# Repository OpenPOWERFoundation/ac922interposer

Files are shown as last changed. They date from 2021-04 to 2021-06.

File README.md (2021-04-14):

# ac922interposer

The purpose of this design is to enable the AC922 to accept a DC-SCM v1.0 hardware management module.  This enables a developement
platform for software development.

For connection with a DC-SCM, the DC-SCM v1.0 release design specifies the connector as an SFF-TA-1002 compliant 4C+ connector. The 4C+ connector is a 4C compliant connector with an additional 28-pin “OCP bay” defined in the OCP NIC 3.0 specification.  The right-angled variety allows for the DC-SCM to lay within the BMC cage assembly.  This can be implemented with TE 2336568-1.

References:

DC-SCM 0.95 Draft Specification:
https://www.opencompute.org/documents/ocp-dc-scm-spec-rev-0-95-pdf

DC-SCM 2.0 Draft Specification:
https://drive.google.com/file/d/1UkFgAFKh8qz4mAXdvodYsW0fg8XhyVf2/view?usp=sharing

AC922 Specification:
see OpenPower website

SFF-TA-1002 Protocol Agnostic Multi-Lane High Speed Connector
https://members.snia.org/document/dl/27231

AntMicro Design Specification:
https://github.com/antmicro/artix-dc-scm.git

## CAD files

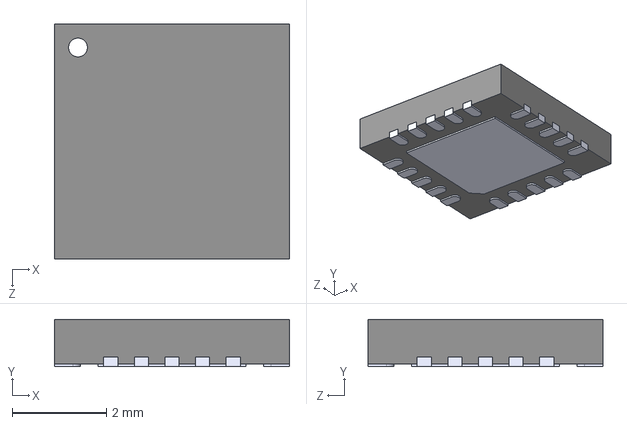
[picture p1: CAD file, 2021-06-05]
3D/TPS7A7100RGWR.STEP
5.00 x 1.00 x 5.00 mm

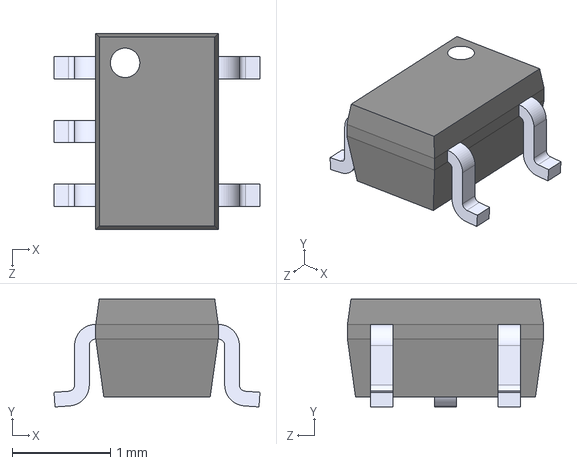
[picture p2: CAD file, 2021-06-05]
kicad-TI_TPS3801/TPS3801K33DCKR.step
2.10 x 1.10 x 2.00 mm

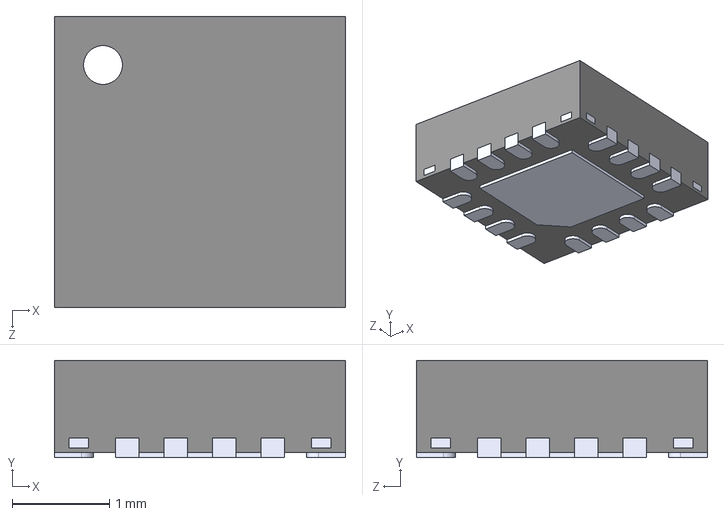
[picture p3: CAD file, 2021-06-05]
3D/TPS7A7100RGTR.STEP
3.00 x 1.00 x 3.00 mm

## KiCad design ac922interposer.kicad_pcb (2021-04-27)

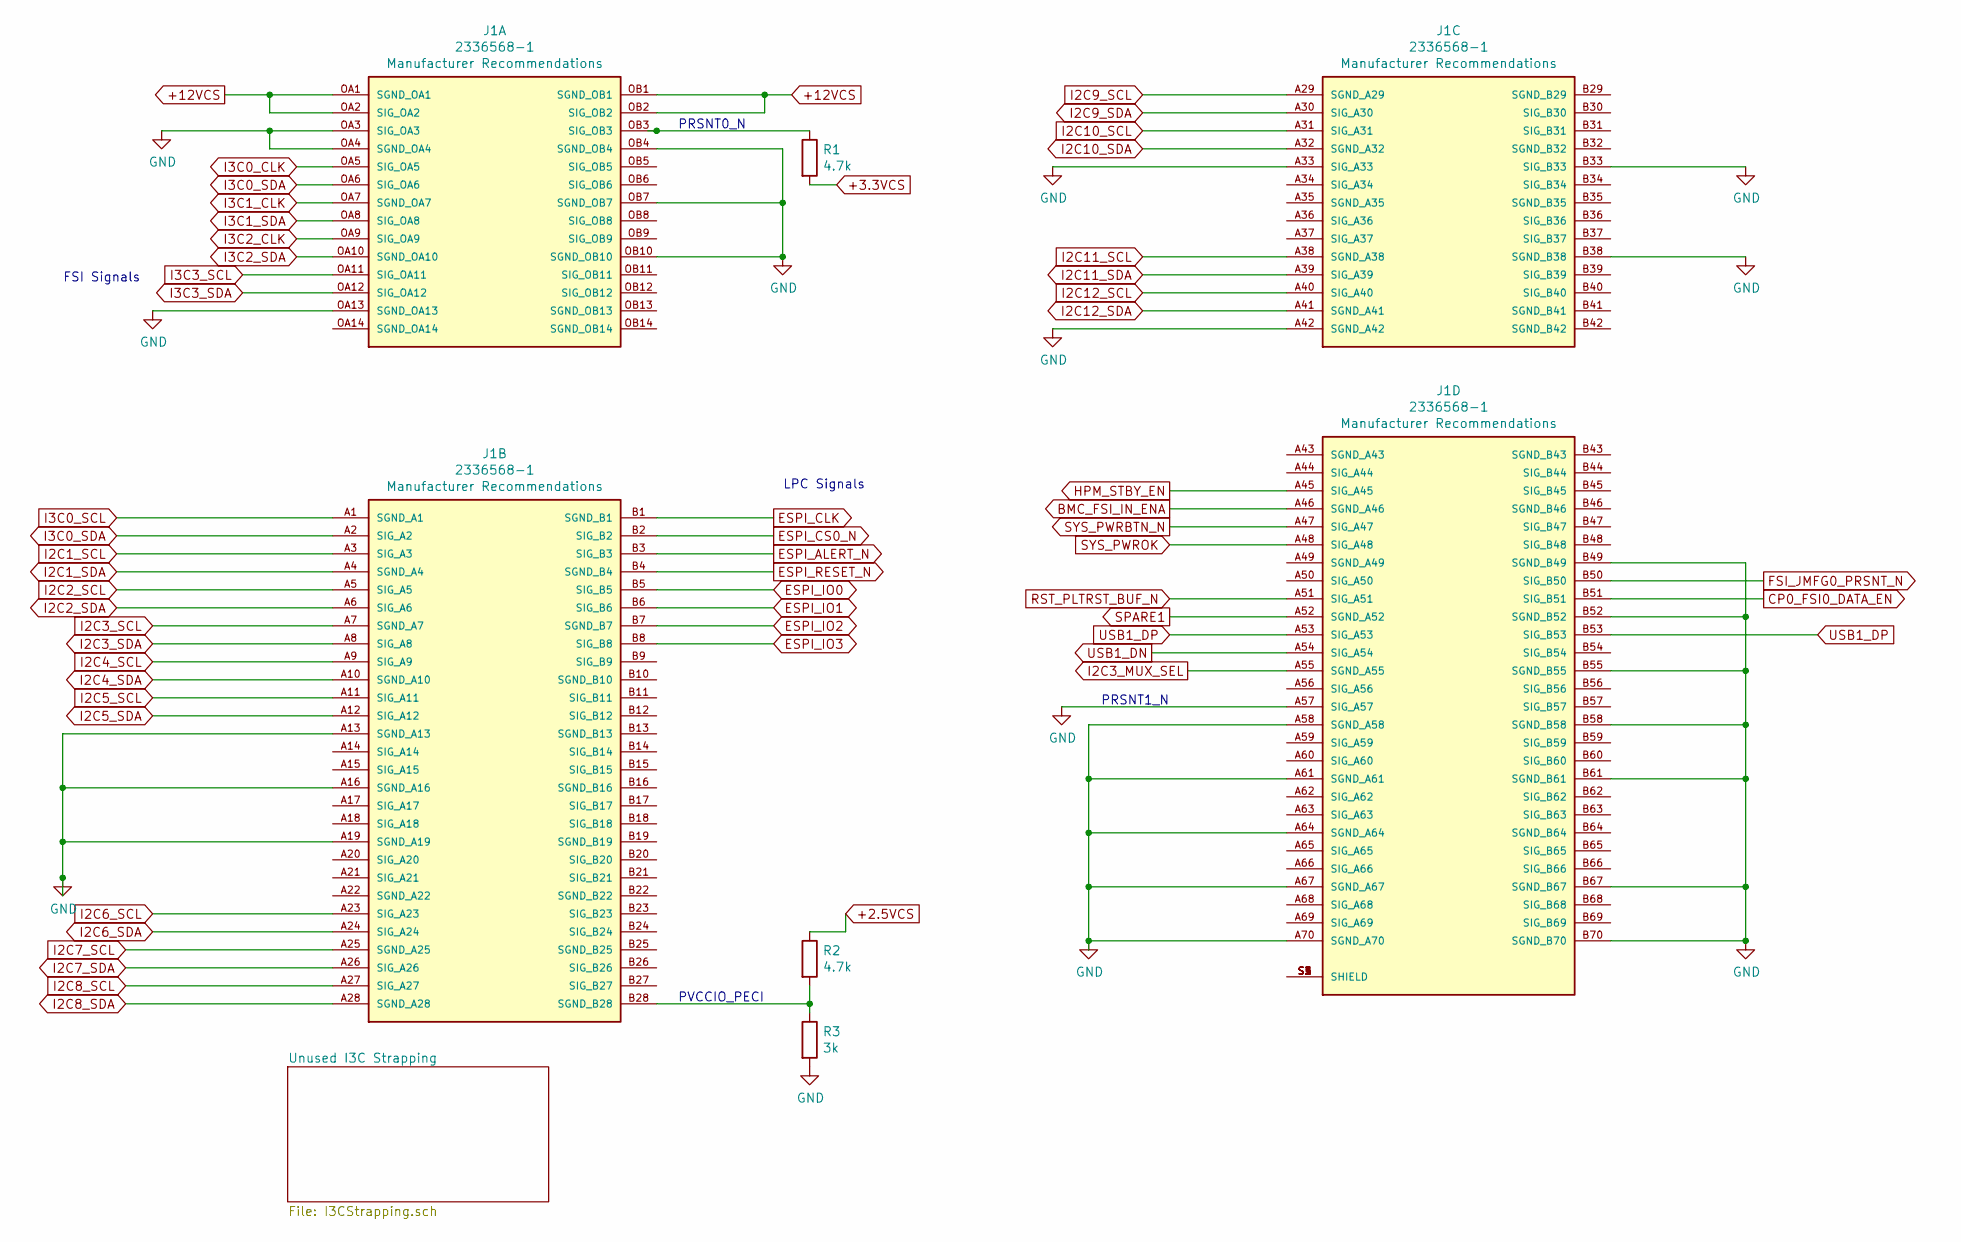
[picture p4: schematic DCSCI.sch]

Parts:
J1: 2336568-1; TE_2336568-1; PARTREV A
R1, R2: 4.7k; R_0805_2012Metric
R3: 3k; R_0805_2012Metric

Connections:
+3.3VCS: R1.2; also elsewhere on the board
+12VCS: J1.OA1 (SGND_OA1), J1.OA2 (SIG_OA2), J1.OB1 (SGND_OB1), J1.OB2 (SIG_OB2); also elsewhere on the board
BMC_FSI_IN_ENA: J1.A46 (SGND_A46); also elsewhere on the board
CP0_FSI0_DATA_EN: J1.B51 (SIG_B51); also elsewhere on the board
ESPI_ALERT_N: J1.B3 (SIG_B3); also elsewhere on the board
ESPI_CLK: J1.B1 (SGND_B1); also elsewhere on the board
ESPI_CS0_N: J1.B2 (SIG_B2); also elsewhere on the board
ESPI_IO1: J1.B6 (SIG_B6); also elsewhere on the board
ESPI_IO2: J1.B7 (SGND_B7); also elsewhere on the board
ESPI_IO3: J1.B8 (SIG_B8); also elsewhere on the board
ESPI_RESET_N: J1.B4 (SGND_B4); also elsewhere on the board
FSI_JMFG0_PRSNT_N: J1.B50 (SIG_B50); also elsewhere on the board
HPM_STBY_EN: J1.A45 (SIG_A45); also elsewhere on the board
I2C1_SCL: J1.A3 (SIG_A3); also elsewhere on the board
I2C1_SDA: J1.A4 (SGND_A4); also elsewhere on the board
I2C2_SCL: J1.A5 (SIG_A5); also elsewhere on the board
I2C2_SDA: J1.A6 (SIG_A6); also elsewhere on the board
I2C3_MUX_SEL: J1.A55 (SGND_A55); also elsewhere on the board
I2C3_SCL: J1.A7 (SGND_A7); also elsewhere on the board
I2C3_SDA: J1.A8 (SIG_A8); also elsewhere on the board
I2C4_SCL: J1.A9 (SIG_A9); also elsewhere on the board
I2C4_SDA: J1.A10 (SGND_A10); also elsewhere on the board
I2C5_SCL: J1.A11 (SIG_A11); also elsewhere on the board
I2C5_SDA: J1.A12 (SIG_A12); also elsewhere on the board
I2C6_SCL: J1.A23 (SIG_A23); also elsewhere on the board
I2C6_SDA: J1.A24 (SIG_A24); also elsewhere on the board
I2C7_SCL: J1.A25 (SGND_A25)
I2C7_SDA: J1.A26 (SIG_A26)
I2C8_SCL: J1.A27 (SIG_A27)
I2C8_SDA: J1.A28 (SGND_A28)
I2C9_SCL: J1.A29 (SGND_A29)
I2C9_SDA: J1.A30 (SIG_A30)
I2C10_SCL: J1.A31 (SIG_A31); also elsewhere on the board
I2C10_SDA: J1.A32 (SGND_A32); also elsewhere on the board
I2C11_SCL: J1.A38 (SGND_A38); also elsewhere on the board
I2C11_SDA: J1.A39 (SIG_A39); also elsewhere on the board
I2C12_SCL: J1.A40 (SIG_A40); also elsewhere on the board
I2C12_SDA: J1.A41 (SGND_A41); also elsewhere on the board
I3C0_CLK: J1.OA5 (SIG_OA5); also elsewhere on the board
I3C0_SCL: J1.A1 (SGND_A1)
I3C0_SDA: J1.A2 (SIG_A2), J1.OA6 (SIG_OA6); also elsewhere on the board
I3C1_CLK: J1.OA7 (SGND_OA7); also elsewhere on the board
I3C1_SDA: J1.OA8 (SIG_OA8); also elsewhere on the board
I3C2_CLK: J1.OA9 (SIG_OA9); also elsewhere on the board
I3C2_SDA: J1.OA10 (SGND_OA10); also elsewhere on the board
I3C3_SCL: J1.OA11 (SIG_OA11); also elsewhere on the board
I3C3_SDA: J1.OA12 (SIG_OA12); also elsewhere on the board
unnamed: J1.B28 (SGND_B28), R2.2, R3.1
unnamed: J1.OB3 (SIG_OB3), R1.1
unnamed: J1.S1 (SHIELD), J1.S2 (SHIELD), J1.S3 (SHIELD), J1.S4 (SHIELD), J1.S5 (SHIELD)
RST_PLTRST_BUF_N: J1.A51 (SIG_A51); also elsewhere on the board
SPARE1: J1.A52 (SGND_A52); also elsewhere on the board
SYS_PWRBTN_N: J1.A47 (SIG_A47); also elsewhere on the board
SYS_PWROK: J1.A48 (SIG_A48); also elsewhere on the board
USB1_DN: J1.A54 (SIG_A54); also elsewhere on the board
USB1_DP: J1.A53 (SIG_A53), J1.B53 (SIG_B53); also elsewhere on the board

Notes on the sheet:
LPC Signals
FSI Signals
PRSNT1_N
PRSNT0_N
PVCCIO_PECI

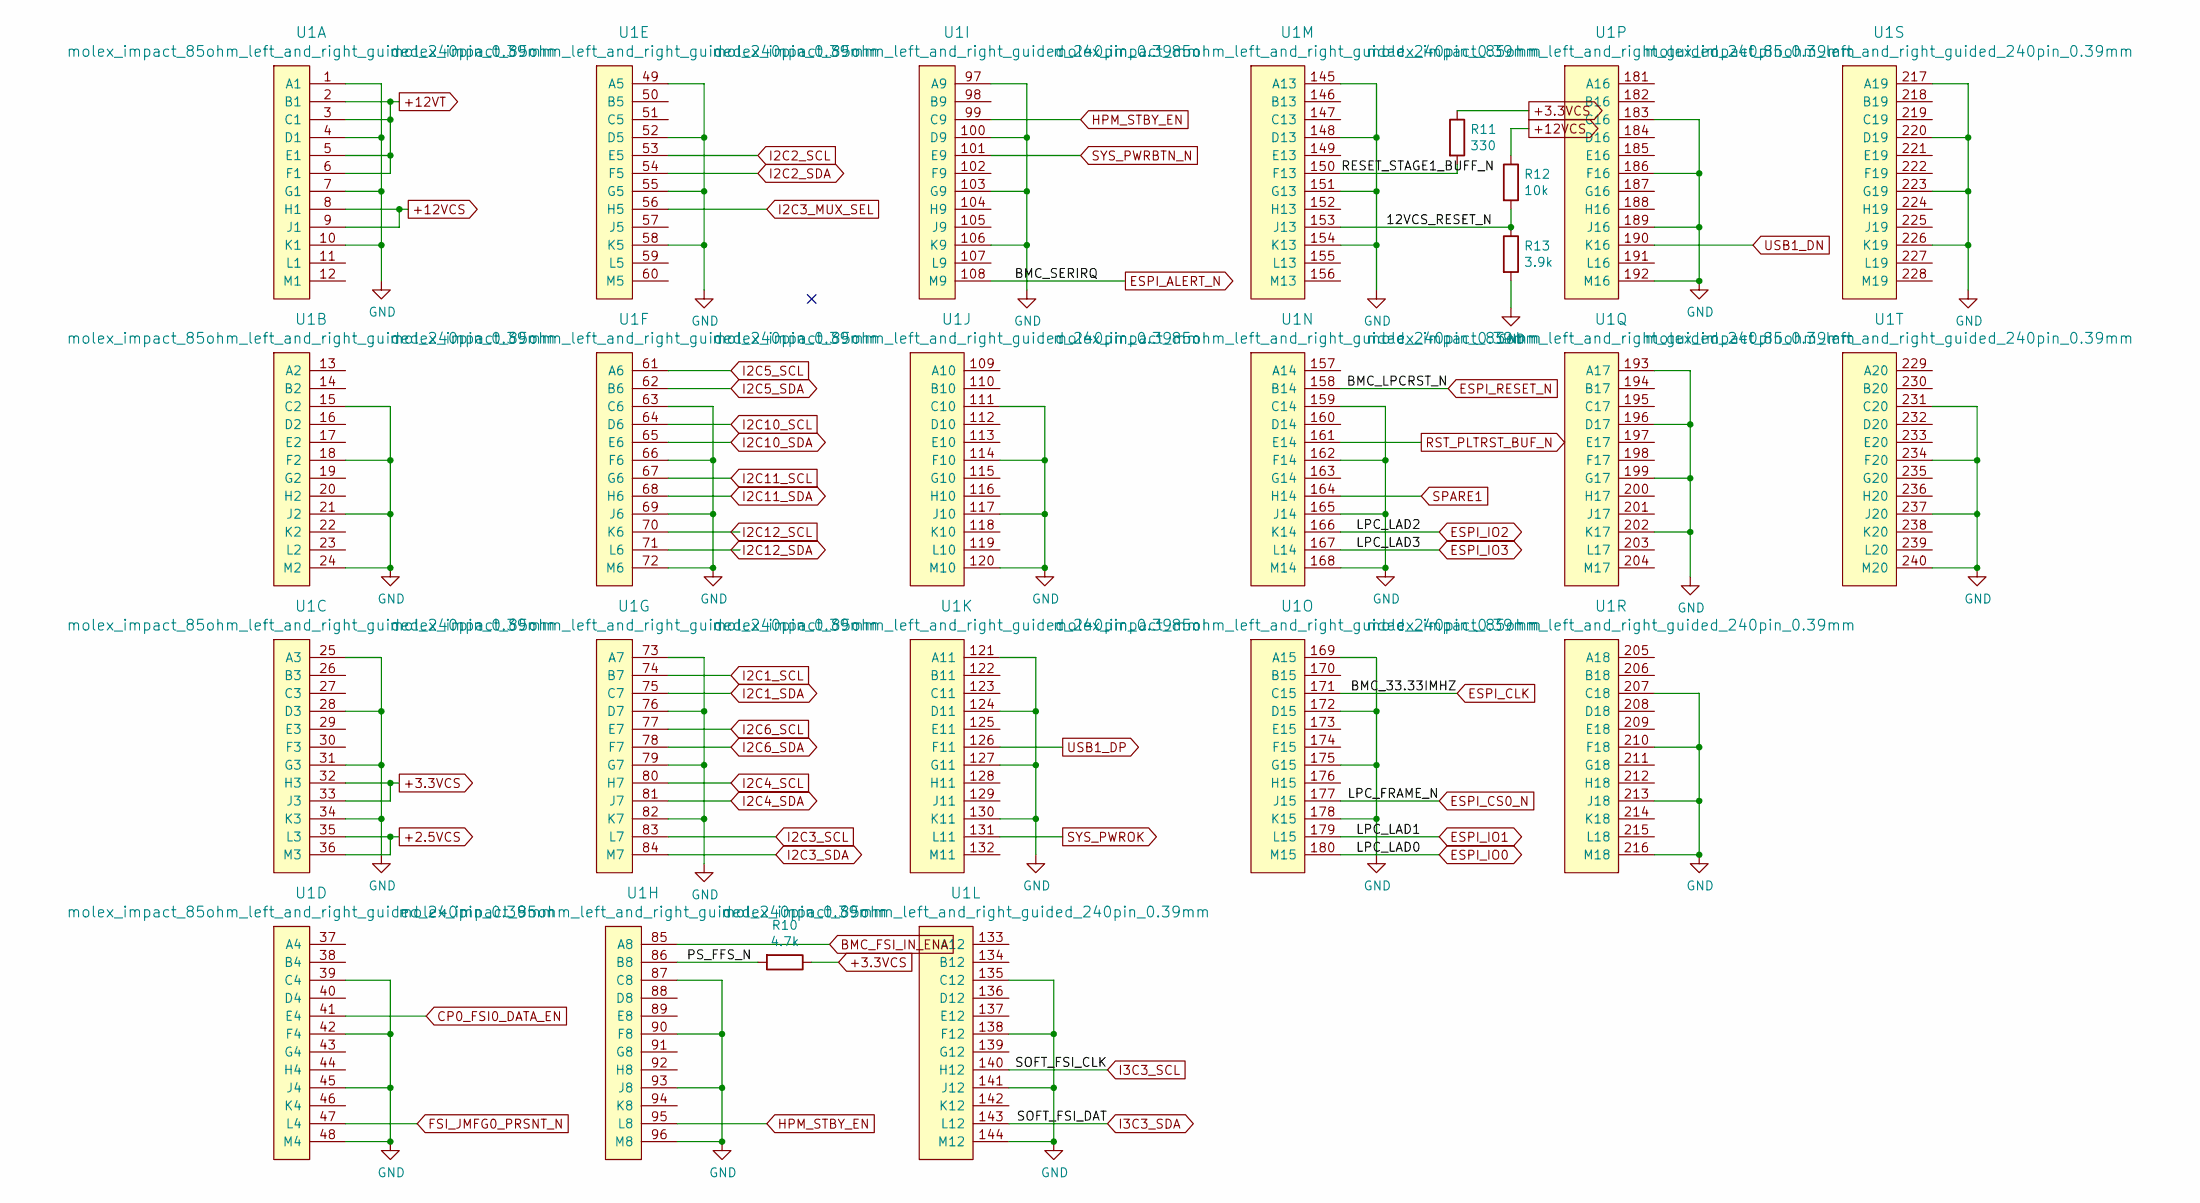
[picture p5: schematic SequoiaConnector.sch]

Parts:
R10: 4.7k; R_0805_2012Metric
R11: 330; R_0805_2012Metric
R12: 10k; R_0805_2012Metric
R13: 3.9k; R_0805_2012Metric
U1: molex_impact_85ohm_left_and_right_guided_240pin_0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; molex_impact_85_ohm_left_and_right_guided_240

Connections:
+3.3VCS: R10.1, R11.1, U1.32 (H3), U1.33 (J3); also elsewhere on the board
+12VCS: R12.1, U1.8 (H1), U1.9 (J1); also elsewhere on the board
+12VT: U1.2 (B1), U1.3 (C1), U1.5 (E1), U1.6 (F1)
/Sequoia Connections/12VCS_RESET_N: R12.2, R13.1, U1.153 (J13)
/Sequoia Connections/PS_FFS_N: R10.2, U1.86 (B8)
/Sequoia Connections/RESET_STAGE1_BUFF_N: R11.2, U1.150 (F13)
BMC_FSI_IN_ENA: U1.85 (A8); also elsewhere on the board
CP0_FSI0_DATA_EN: U1.41 (E4); also elsewhere on the board
ESPI_ALERT_N: U1.108 (M9); also elsewhere on the board
ESPI_CLK: U1.171 (C15); also elsewhere on the board
ESPI_CS0_N: U1.177 (J15); also elsewhere on the board
ESPI_IO1: U1.179 (L15); also elsewhere on the board
ESPI_IO2: U1.166 (K14); also elsewhere on the board
ESPI_IO3: U1.167 (L14); also elsewhere on the board
ESPI_RESET_N: U1.158 (B14); also elsewhere on the board
FSI_JMFG0_PRSNT_N: U1.47 (L4); also elsewhere on the board
HPM_STBY_EN: U1.95 (L8), U1.99 (C9); also elsewhere on the board
I2C1_SCL: U1.74 (B7); also elsewhere on the board
I2C1_SDA: U1.75 (C7); also elsewhere on the board
I2C2_SCL: U1.53 (E5); also elsewhere on the board
I2C2_SDA: U1.54 (F5); also elsewhere on the board
I2C3_MUX_SEL: U1.56 (H5); also elsewhere on the board
I2C3_SCL: U1.83 (L7); also elsewhere on the board
I2C3_SDA: U1.84 (M7); also elsewhere on the board
I2C4_SCL: U1.80 (H7); also elsewhere on the board
I2C4_SDA: U1.81 (J7); also elsewhere on the board
I2C5_SCL: U1.61 (A6); also elsewhere on the board
I2C5_SDA: U1.62 (B6); also elsewhere on the board
I2C6_SCL: U1.77 (E7); also elsewhere on the board
I2C6_SDA: U1.78 (F7); also elsewhere on the board
I2C10_SCL: U1.64 (D6); also elsewhere on the board
I2C10_SDA: U1.65 (E6); also elsewhere on the board
I2C11_SCL: U1.67 (G6); also elsewhere on the board
I2C11_SDA: U1.68 (H6); also elsewhere on the board
I2C12_SCL: U1.70 (K6); also elsewhere on the board
I2C12_SDA: U1.71 (L6); also elsewhere on the board
I3C3_SCL: U1.140 (H12); also elsewhere on the board
I3C3_SDA: U1.143 (L12); also elsewhere on the board
RST_PLTRST_BUF_N: U1.161 (E14); also elsewhere on the board
SPARE1: U1.164 (H14); also elsewhere on the board
SYS_PWRBTN_N: U1.101 (E9); also elsewhere on the board
SYS_PWROK: U1.131 (L11); also elsewhere on the board
USB1_DN: U1.190 (K16); also elsewhere on the board
USB1_DP: U1.126 (F11); also elsewhere on the board

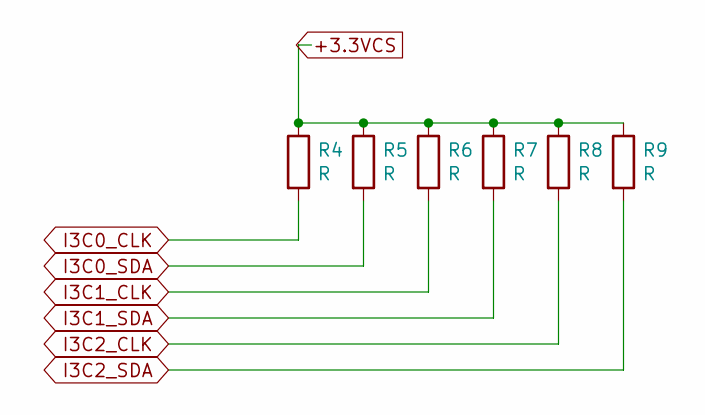
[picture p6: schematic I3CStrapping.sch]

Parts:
R4, R5, R6, R7, R8, R9: R; R_0805_2012Metric

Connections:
I3C0_CLK: R4.2; also elsewhere on the board
I3C0_SDA: R5.2; also elsewhere on the board
I3C1_CLK: R6.2; also elsewhere on the board
I3C1_SDA: R7.2; also elsewhere on the board
I3C2_CLK: R8.2; also elsewhere on the board
I3C2_SDA: R9.2; also elsewhere on the board
unnamed: R4.1, R5.1, R6.1, R7.1, R8.1, R9.1

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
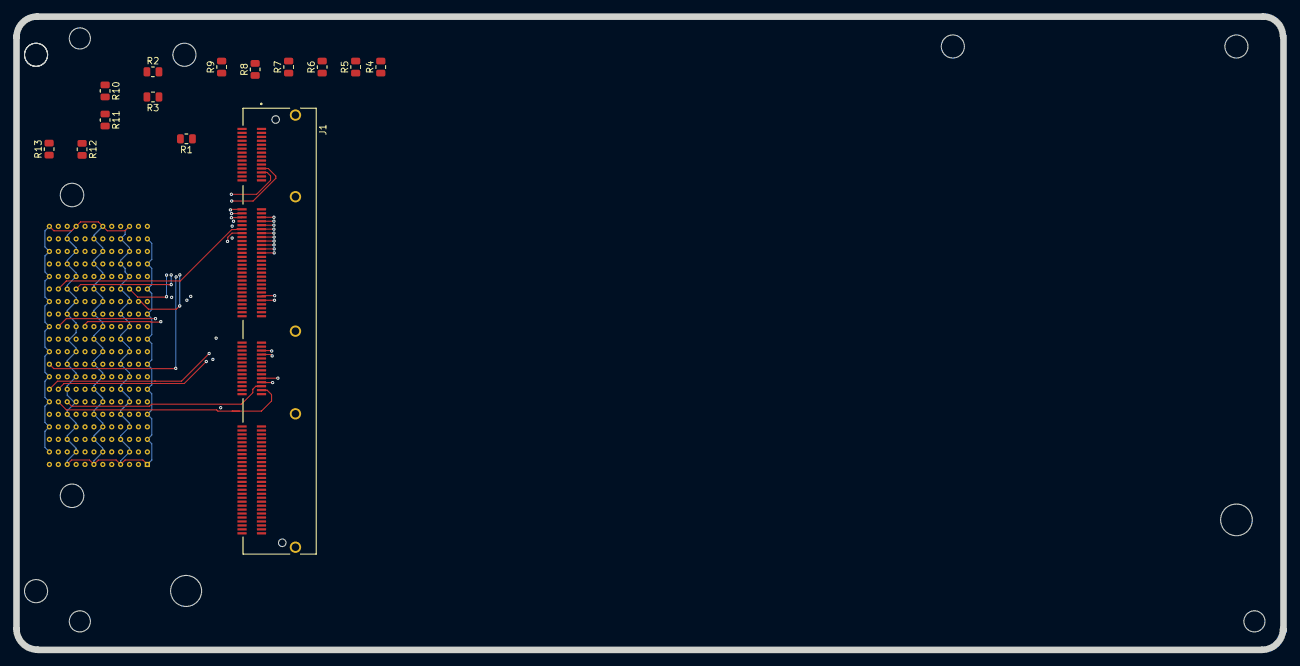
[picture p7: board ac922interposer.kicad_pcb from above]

Board: 6 copper layers, 192.1 x 96.0 mm, 15 parts (1 on the bottom side), 57 nets.

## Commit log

2021-04-14 initial schematic
    [DCSCI.sch, I3CStrapping.sch, SequoiaConnector.sch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]
2021-04-19 Removed extra junctions that were shorting 2.5v to gnd.
    [SequoiaConnector.sch, ac922interposer.kicad_pcb]
2021-04-20 Placement, initial holes, and some traces.
    [ac922interposer.kicad_pcb]
2021-04-27 Update some routes. Perhaps some schematic.
    [ac922interposer.kicad_pcb]
2021-05-01 first schematic review and first routing
2021-06-05 Design clean, reviewed, and issued to Fab at JLCPCB.
    [TPS3801K33DCKR.step, TPS7A7100RGTR.STEP, TPS7A7100RGWR.STEP]
2022-03-29 Interposer 240pin connector pinout
2022-04-12 240pin connector pinout
2022-04-12 Delete '240pin connector pinout.docx
    This needs to be in plain txt, not docx. I added the plain text version and am now deleting the .docx version.
2022-04-18 Correct 240pin for BMC card (aka Boxelder)
    Note the connector is actually split into 2 with a left and right half -- each containing 120pins. If the pin reference is blank, then the pin is a NC.

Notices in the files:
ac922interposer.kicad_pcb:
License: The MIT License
